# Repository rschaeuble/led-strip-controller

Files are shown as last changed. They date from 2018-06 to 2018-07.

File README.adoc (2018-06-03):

= LED Strip Controller

An LED strip controller for up to three RGB[W] LED strips, controlled over WiFi + MQTT.

== Current State

* Hardware
** Circuit schematic: nearly complete (for an initial version)
*** A switch mode power supply module needs to be selected.
*** External connectors need to be selected; right now the schematic uses simple pin headers.
** PCB layout: not yet started.
* Software: prototype exists; will be released in the following weeks after some cleanup and polishing. 

== Features

Up to three independently controllable LED strips: ::
+
--
When decorating shelves, TV racks or similar with LED strips, having several
shorter strips glowing in different colors can look nicer than having one longer strip.
However, with usual LED strip controllers, each strip requires its own controller plus power supply. In the end, all those small boxes and their
power bricks don't really look all that pretty.

With this controller, three separate LED strips can be driven with just one small box and its power brick.
--

MQTT interface: ::
+
--
The controller connects (via WiFi) to an MQTT broker, from which it receives
commands and to where it posts its current state.

Right now, the controller supports the following message formats:

* https://www.home-assistant.io/components/light.mqtt_json/[MQTT JSON Light], with support for brightness, RGB colors and white value.

Support for other message formats (e.g. https://www.home-assistant.io/components/light.mqtt/[MQTT Light])
might follow later.

--

== Documentation

* Hardware: link:hardware/led-strip-controller-esp8266/README.adoc[led-strip-controller-esp8266].

== Licenses

=== Software

The software in this repository, with the exception of included third-party works, is licensed under
the link:LICENSE_software.txt[MIT license].

=== Hardware

The hardware designs (schematics, PCB layouts, symbols and footprints etc.) in this repository,
with the exception of included third-party works, are licensed under the
link:http://creativecommons.org/licenses/by-sa/4.0/[Creative Commons Attribution-ShareAlike 4.0 International License].

=== Third-Party Works

Included third-party works (in the directory `3rd-party`) are licensed under their own terms.
Please check the respective licenses.

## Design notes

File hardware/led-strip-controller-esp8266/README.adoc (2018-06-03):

= ESP8266 based LED Strip Controller
:toc:
:sectnums:
:icons: font

== Hardware Design

Schematic and PCB layout are created using KiCad 5. The project files can be found in the `hardware` directory.

Exports for viewing without KiCad also exist. These should (hopefully) be pretty up-to-date.

.Exports:
* link:exports/led-strip-controller-esp8266.pdf[Schematic]

== Main Components

ESP-WROOM-02::
+
--
Microcontroller with built-in WiFi.
--

PCA9685::
+
--
PWM LED controller with 16 channels and I^2^C bus interface.

As the ESP8266 does not have enough pins to drive 12 LED channels (3 * RGBW), a dedicated chip has to do this work.
--

== Power Supply

The circuit consists of two power nets: a 12{nbsp}V net for the LED strips and a 3.3{nbsp}V net for everything else.

The 12{nbsp}V are provided by an external power supply. The LED strips are directly connected to this power rail.

The 3.3{nbsp}V are provided by an on-circuit power regulator whose input is connected to the 12{nbsp}V rail.
With a voltage difference of about 9{nbsp}V and up to 500{nbsp}mA current draw by the ESP8266 alone,
a linear regulator is too inefficient, so a switching mode regulator is used.

.Current draw of individual components:
* ESP-WROOM-02: 500{nbsp}mA
* PCA9685: 10{nbsp}mA (just the chip, without any driven LEDs)
* One or two status LEDs: 40{nbsp}mA

Adding some buffer, an 800{nbsp}mA power supply should suffice easily.

== Design Consideration

This section is a collection of various design considerations.

=== Switch Mode Power Supply: build your own or buy (OPEN)

As this is my first real hardware project and given my complete lack of experience with switch mode power supplies,
I ruled out building my own regulator circuit (e.g. based on LM2595 or LM2675).
Instead, an all-in-one regulator module will be used.

.Module Candidates
[%header,cols="2,1,1a,1,3a"]
|===
|Name +
(Manufacturer)
|Datasheet
|Distributor 
|Price
|Notes

|VXO7803-1000 +
(CUI)
|https://www.cui.com/product/resource/digikeypdf/vxo78-1000.pdf[Datasheet]
|https://www.digikey.de/product-detail/de/cui-inc/VXO7803-1000/102-4257-ND/7350296[Digi-Key],
https://www.mouser.de/ProductDetail/CUI/VXO7803-1000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[Mouser]
|2.22-2.35{nbsp}€
|

|VX7803-1000 +
(CUI)
|https://www.cui.com/product/resource/digikeypdf/vx78-1000.pdf[Datasheet]
|https://www.digikey.de/product-detail/de/cui-inc/VX7803-1000/102-4252-ND/7350291[Digi-Key]
|2,80{nbsp}€
|

|R-78E3.3-1.0 +
(Recom Power)
|https://www.recom-power.com/pdf/Innoline/R-78Exx-1.0.pdf[Datasheet]
|https://www.digikey.de/product-detail/de/recom-power/R-78E3.3-1.0/945-2409-5-ND/5327711[Digi-Key],
https://www.mouser.de/ProductDetail/RECOM-Power/R-78E33-10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[Mouser]
|2,67-2,80{nbsp}€
|

|MEZD71201A-F +
(Monolithic Power Systems)
|http://www.monolithicpower.com/pub/media/document/mEZD71201Ar1.5.pdf[Datasheet]
|https://www.digikey.de/product-detail/de/monolithic-power-systems-inc/MEZD71201A-F/1589-1457-ND/6823820[Digi-Key],
https://www.mouser.de/ProductDetail/Monolithic-Power-Systems-MPS/mEZD71201A-F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[Mouser]
|2,76-2,90{nbsp}€
|

|TR10S3V3 +
(XP Power)
|https://www.xppower.com/Portals/0/pdfs/SF_TR10.pdf[Datasheet]
|https://www.digikey.de/product-detail/de/xp-power/TR10S3V3/1470-3970-ND/6707494[Digi-Key]
|3,40{nbsp}€
|

|===

Product search:

* https://www.digikey.de/products/de/power-supplies-board-mount/dc-dc-converters/922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[Digi-Key]
* https://www.mouser.de/Power/DC-DC-Converters/_/N-brvxe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|0[Mouser] 

=== Overload Protection for LED strips (OPEN)

If the LED strips connected to the controller draw more power than the power supply and/or the circuitry
can handle, this could potentially cause damage.

To prevent this, some kind of current limiter could be added to the circuitry feeding the LED strips.

.Open questions:
* How would the overcurrent protection work? Autonomous hardware, or with support from the firmware?
* How about a current meter (with a I^2^C interface) that the firmware could read out? The current power draw
  could be reported via MQTT, providing for a nice little feature.

=== ESD Protection

The following connections are accessible when the controller is inside a closed enclosure:

* LED strip connectors.
* Power supply jack.
* Programming lines:
** RX/TX
** GND
** Reset
** Firmware flashing mode selector

While ESD protection for a simple and cheap product as this is probably a bit overkill,
adding it would teach me something new, so I'll likely do it.

To do:

* Learn about different ESD protection techniques
** Diodes to V+, one to V-.
** Diodes only to V-.
* Extend schematic.

.Reading List
* http://www.onsemi.com/pub/Collateral/TND335-D.PDF
* https://www.onsemi.com/pub/Collateral/AND8231-D.PDF

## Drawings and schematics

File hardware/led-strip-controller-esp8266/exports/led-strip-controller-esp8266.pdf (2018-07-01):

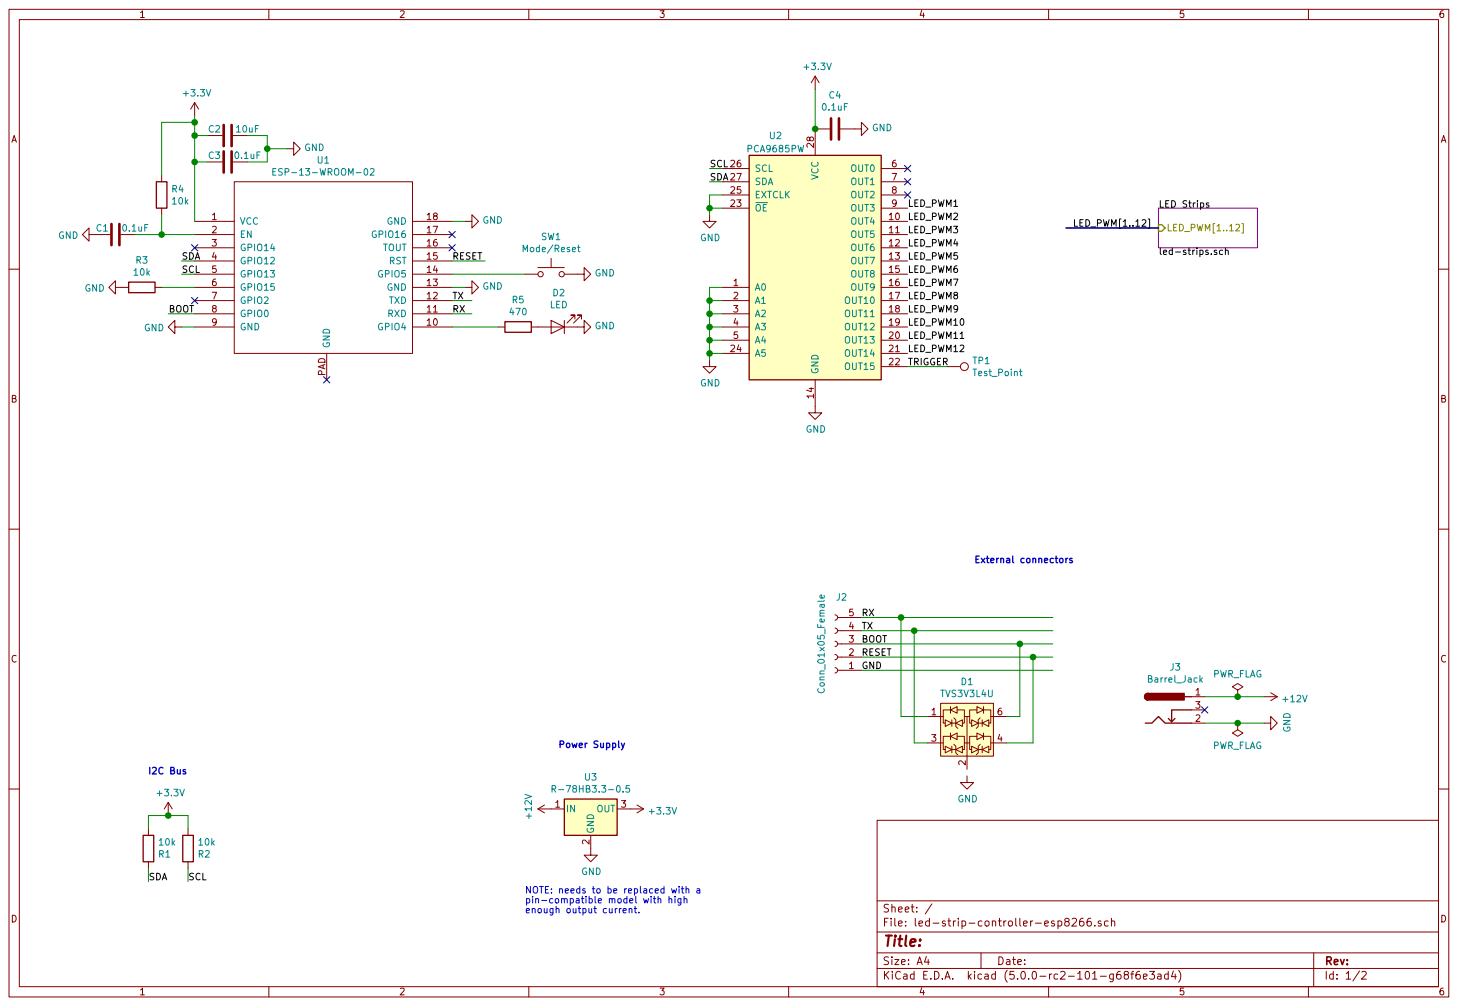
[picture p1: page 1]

+3.3V NOTE: needs to be replaced with a

enough output current. GND

pin-compatible model with high

File: led-strip-controller-esp8266.sch Sheet: /
Id: 1/2 Title:

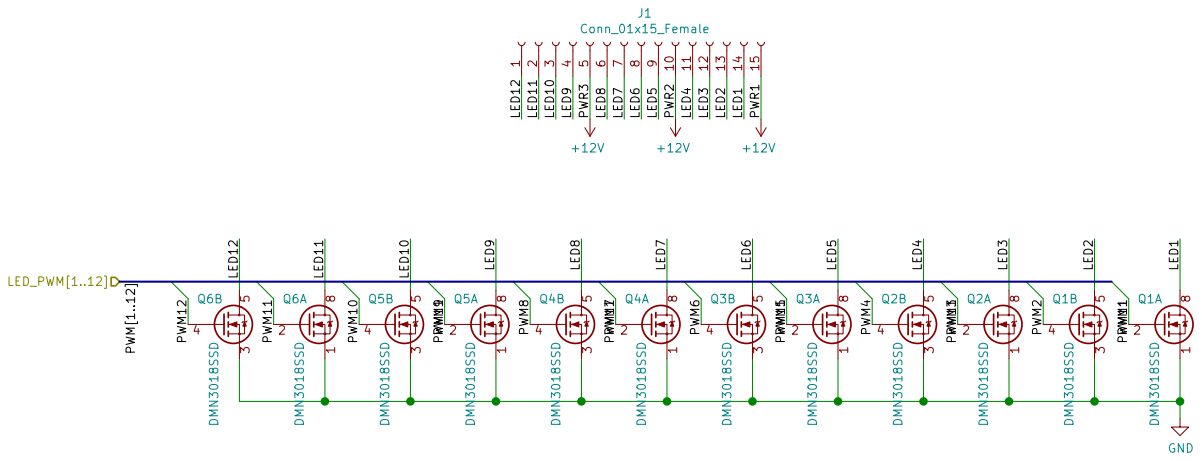
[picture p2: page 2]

Sheet: /LED Strips/
File: led-strips.sch
Id: 2/2 Title:

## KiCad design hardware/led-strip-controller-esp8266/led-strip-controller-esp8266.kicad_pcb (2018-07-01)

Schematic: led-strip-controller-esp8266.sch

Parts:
C1, C3, C4: 0.1uF; C_0805_2012Metric_Pad1.29x1.40mm_HandSolder
C2: 10uF; C_0805_2012Metric_Pad1.29x1.40mm_HandSolder
D1: TVS3V3L4U; TSOP-6_1.65x3.05mm_P0.95mm
D2: LED; LED_0805_2012Metric
J2: Conn_01x05_Female; PinHeader_1x05_P1.00mm_Vertical
J3: Barrel_Jack; BarrelJack_Horizontal
R1, R2, R3, R4: 10k; R_0805_2012Metric_Pad1.29x1.40mm_HandSolder
R5: 470; R_0805_2012Metric_Pad1.29x1.40mm_HandSolder
TP1: Test_Point; Pin_D1.0mm_L10.0mm
U1: ESP-13-WROOM-02
U2: PCA9685PW; TSSOP-28_4.4x9.7mm_P0.65mm
U3: R-78HB3.3-0.5; Converter_DCDC_RECOM_R-78HB-0.5_THT

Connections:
+3V3: C2.2, C3.2, C4.1, R1.2, R2.2, R4.1, U1.1, U2.28, U3.3 (OUT)
+12V: J3.1, U3.1 (IN); also elsewhere on the board
/BOOT: D1.6, J2.3, U1.8
/LED_PWM1: U2.9, U2.11, U2.13, U2.16, U2.18, U2.20; also elsewhere on the board
/LED_PWM2: U2.10; also elsewhere on the board
/LED_PWM4: U2.12; also elsewhere on the board
/LED_PWM6: U2.15; also elsewhere on the board
/LED_PWM8: U2.17; also elsewhere on the board
/LED_PWM10: U2.19; also elsewhere on the board
/LED_PWM12: U2.21; also elsewhere on the board
/RESET: D1.4, J2.2, U1.15
/RX: D1.1, J2.5, U1.11
/SCL: R2.1, U1.5, U2.26
/SDA: R1.1, U1.4, U2.27
/TRIGGER: TP1.1, U2.22
/TX: D1.3, J2.4, U1.12
unnamed: C1.1, R4.2, U1.2
unnamed: D2.2, R5.1
unnamed: R3.1, U1.6
unnamed: R5.2, U1.10

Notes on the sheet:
I2C Bus
NOTE: needs to be replaced with a pin-compatible model with high enough output current.
External connectors
Power Supply

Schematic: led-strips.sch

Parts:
J1: Conn_01x15_Female; PinHeader_1x15_P1.00mm_Vertical
Q1, Q2, Q3, Q4, Q5, Q6: DMN3018SSD; SOIC-8_3.9x4.9mm_P1.27mm

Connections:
+12V: J1.5, J1.10, J1.15; also elsewhere on the board
/LED Strips/LED1: J1.14, Q1.7 (D1), Q1.8 (D1)
/LED Strips/LED2: J1.13, Q1.5 (D2), Q1.6 (D2)
/LED Strips/LED3: J1.12, Q2.7 (D1), Q2.8 (D1)
/LED Strips/LED4: J1.11, Q2.5 (D2), Q2.6 (D2)
/LED Strips/LED5: J1.9, Q3.7 (D1), Q3.8 (D1)
/LED Strips/LED6: J1.8, Q3.5 (D2), Q3.6 (D2)
/LED Strips/LED7: J1.7, Q4.7 (D1), Q4.8 (D1)
/LED Strips/LED8: J1.6, Q4.5 (D2), Q4.6 (D2)
/LED Strips/LED9: J1.4, Q5.7 (D1), Q5.8 (D1)
/LED Strips/LED10: J1.3, Q5.5 (D2), Q5.6 (D2)
/LED Strips/LED11: J1.2, Q6.7 (D1), Q6.8 (D1)
/LED Strips/LED12: J1.1, Q6.5 (D2), Q6.6 (D2)
/LED_PWM1: Q1.2 (G1), Q2.2 (G1), Q3.2 (G1), Q4.2 (G1), Q5.2 (G1), Q6.2 (G1); also elsewhere on the board
/LED_PWM2: Q1.4 (G2); also elsewhere on the board
/LED_PWM4: Q2.4 (G2); also elsewhere on the board
/LED_PWM6: Q3.4 (G2); also elsewhere on the board
/LED_PWM8: Q4.4 (G2); also elsewhere on the board
/LED_PWM10: Q5.4 (G2); also elsewhere on the board
/LED_PWM12: Q6.4 (G2); also elsewhere on the board

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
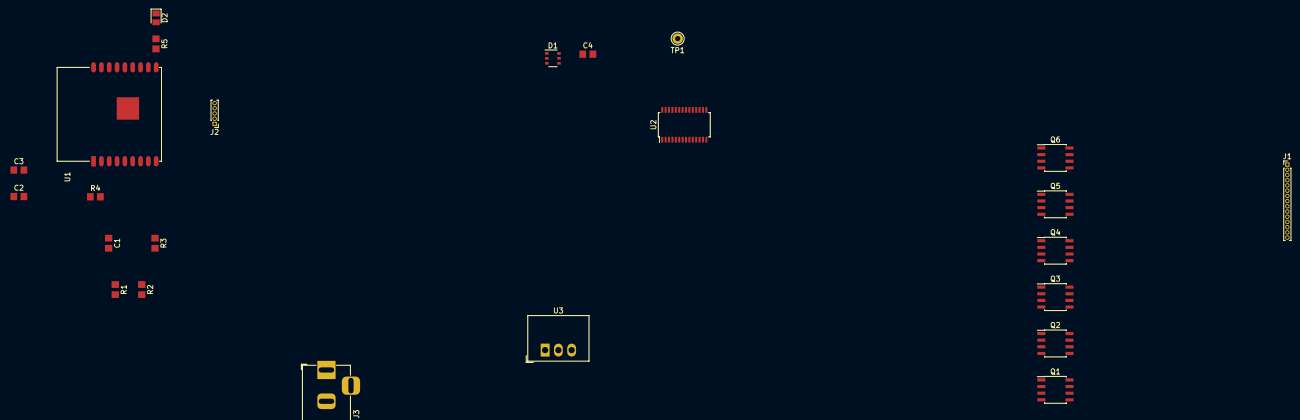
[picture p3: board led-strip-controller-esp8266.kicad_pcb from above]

Board: 2 copper layers, 24 parts (0 on the bottom side), 33 nets, no tracks yet.

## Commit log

2018-05-29 Squashed '3rd-party/kicad-libs/kicad-ESP8266/' content from commit ab37bad
    git-subtree-dir: 3rd-party/kicad-libs/kicad-ESP8266
    git-subtree-split: ab37bad0510ac6d2f79f07f9f6303ad56de5b2df
2018-05-29 Add initial (quite empty) KiCad project.
    [led-strip-controller-esp8266.kicad_pcb, led-strip-controller-esp8266.sch]
2018-05-29 Begin with schematic drawing.
    [led-strip-controller-esp8266.kicad_pcb, led-strip-controller-esp8266.sch, led-strip.sch]
2018-06-02 Document current state in README.
2018-06-02 More work on the schematic.
    [led-strip-controller-esp8266.kicad_pcb, led-strip-controller-esp8266.sch, led-strip.sch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]
2018-06-03 Remove file that's not used any more.
    [led-strip.sch]
2018-06-03 Add power supply module and power jack.
    [led-strip-controller-esp8266.kicad_pcb, led-strip-controller-esp8266.sch]
2018-06-03 Update "current state" section in README.
2018-06-03 Add PDF export of the schematic.
2018-06-03 KiCad project file update.
2018-06-03 Add decoupling capacitor to power supply pin of PCA9685.
    [led-strip-controller-esp8266.sch]
2018-06-03 Add 3.3V rail to external programming interface, and update schematic PDF.
    [led-strip-controller-esp8266.sch]
2018-06-21 Add symbol for Diodes Inc. DMN3018SSD.
2018-06-21 Add TVS3V3L4U TVS diode.
2018-06-21 Add TVS diode and new MOSFET array to schematic.
    [led-strip-controller-esp8266.kicad_pcb, led-strip-controller-esp8266.sch, led-strips.sch]
2018-07-01 Add status LED and resistor.
    [led-strip-controller-esp8266.kicad_pcb, led-strip-controller-esp8266.sch]
2018-07-01 Add a mode/reset button.
    [led-strip-controller-esp8266.sch]
2018-07-01 Updated schematics PDF.
